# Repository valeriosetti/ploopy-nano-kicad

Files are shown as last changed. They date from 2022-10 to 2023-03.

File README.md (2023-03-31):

# What's Ploopy Nano?

Ploopy nano is a compact trackball mouse whose hardware project (electronics & mechanics) is completely open source. The original github project can be found here:

<https://github.com/ploopyco/nano-trackball>

# Why a clone?

There are a couple of reasons for this:

1. Albeit the original project is open, it's designed for Altium software. The goal of this project is to clone that design as much as possible, but in KiCAD

1. Since I would like to test the BTU mod and I had that printed from an external online service, it didn't make much sense in my opinion to buy the whole kit just for the PCB. That's why I prefered to do it on my own

# What are the differences with the original design?

For technical and components' availability reasons, this design is slightly different from the original version. Here's the main points:

* USB typeC connector instead of microUSB
    * that's my preference
    * of course the USB speed is not changed, it's just a connector replacement
* debug UART pinheader
    * it's always useful to have it in case some debug is required
* replaced the 3x2 programmer's pinheader with TPs
    * this is mostly for layout reasons: on one hand the original connector required through holes, whereas TPs are just on one side; on the other hand it's also more flexible to place those 6 TPs
* smaller crystal (in size)
    * I could not find the original crystal available on JLCPCB, so I switched to an equivalent one which unfortunately has smaller footprint

# Board's design

The placement of componenets on the board was obtained using FreeCAD:

* I loaded PCB's step file into FreeCAD
* Generated a 2D top view of the PCB
* Exported into DXF
* Impoted the DXF into KiCAD

Similarly I did also for the layout of the PCB itself. In this case:

* I imported the layout of the board in FreeCAD using KiCadStepUp plugin
* Ridesigned the edges of the board
* Exported again into the *kicad_pcb* file
* Reopened KiCAD with new shape

# Extra

The **jlcpcb** folder contain gerber, BOM and placement files I used to order from JLCPCB site. They have been automatically generated from the specific KiCAD's extension.

Some components, likes the ATmega32U4 or the LED, are not present in the BOM because they're out of stock on JLCPCB, so I'm planning to buy them separately and solder manually.

# Results

Since the description is quite long I decided to create a specific [readme file](result/README.md) for this in order to explain also the step I did for the bringup.

# Final thoughts

Even thought it's a nice project, there are a few things which might be known for anyone who attempts at building it:

* the ADNS-5050 is absolutely impossible to find, at least here in Europe. I ended up buying the ADNS-5020 which is pin to pin compatible, but also for that one it was a mess: the 1st order from Aliexpress was lost somewhere and the 2nd one took some time to be delivered (which is not so common nowadays when buying from Aliexpress)
* the 38 mm (1.5 inches) ball is not easy to find as well. I know, those are used for small billiard balls, but if you don't want to buy an entire set of billiard ball for just using 1, then good luck in finding something

In general I strongly suggest to take a look and consider also jfedor2's projects:
* they are based on a RP2040 microcontroller, which you can find at almost the same price of the ATMEGA, but it's way more powerfull 
* he provides the project directly for KiCAD with also gerber files for JLCPCB--> https://github.com/jfedor2/rp2040-pmw3360
* he used another sensor, PMW3360, which seems way more easy to find online

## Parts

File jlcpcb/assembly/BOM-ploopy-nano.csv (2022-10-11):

Comment | Designator | Footprint | LCSC
FerriteBead | FB1,FB2,FB3 | R_0603_1608Metric | C107335
0.1u | C1,C10,C2,C4,C5,C6,C7,C9 | C_0603_1608Metric | C14663
1u | C12,C3 | C_0603_1608Metric | C15849
20p | C13,C14 | C_0603_1608Metric | C1603
TYPE-C-31-M-12 | J4 | HRO_TYPE-C-31-M-12 | C165948
47 | R3,R4 | R_0603_1608Metric | C23164
5.1k | R7,R8 | R_0603_1608Metric | C23186
22 | R5,R6 | R_0603_1608Metric | C23345
10k | R1,R2 | R_0603_1608Metric | C25804
IP4220CZ6 | U2 | SOT95P275X110-6N | C558417
ECS-160-12-30B-AGM-TR | Y1 | Crystal_SMD_2520-4Pin_2.5x2.0mm | C655061
10u | C11,C8 | C_0603_1608Metric | C96446

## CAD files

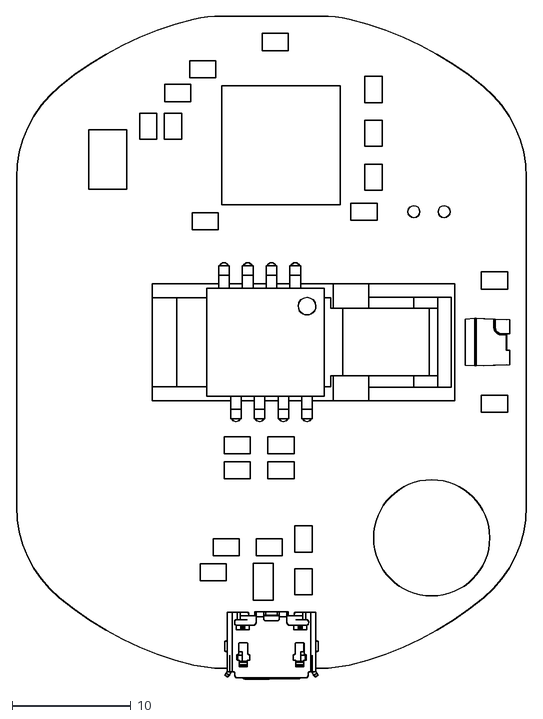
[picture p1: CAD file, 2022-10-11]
docs/original-pcb.dxf
43.0 x 55.9

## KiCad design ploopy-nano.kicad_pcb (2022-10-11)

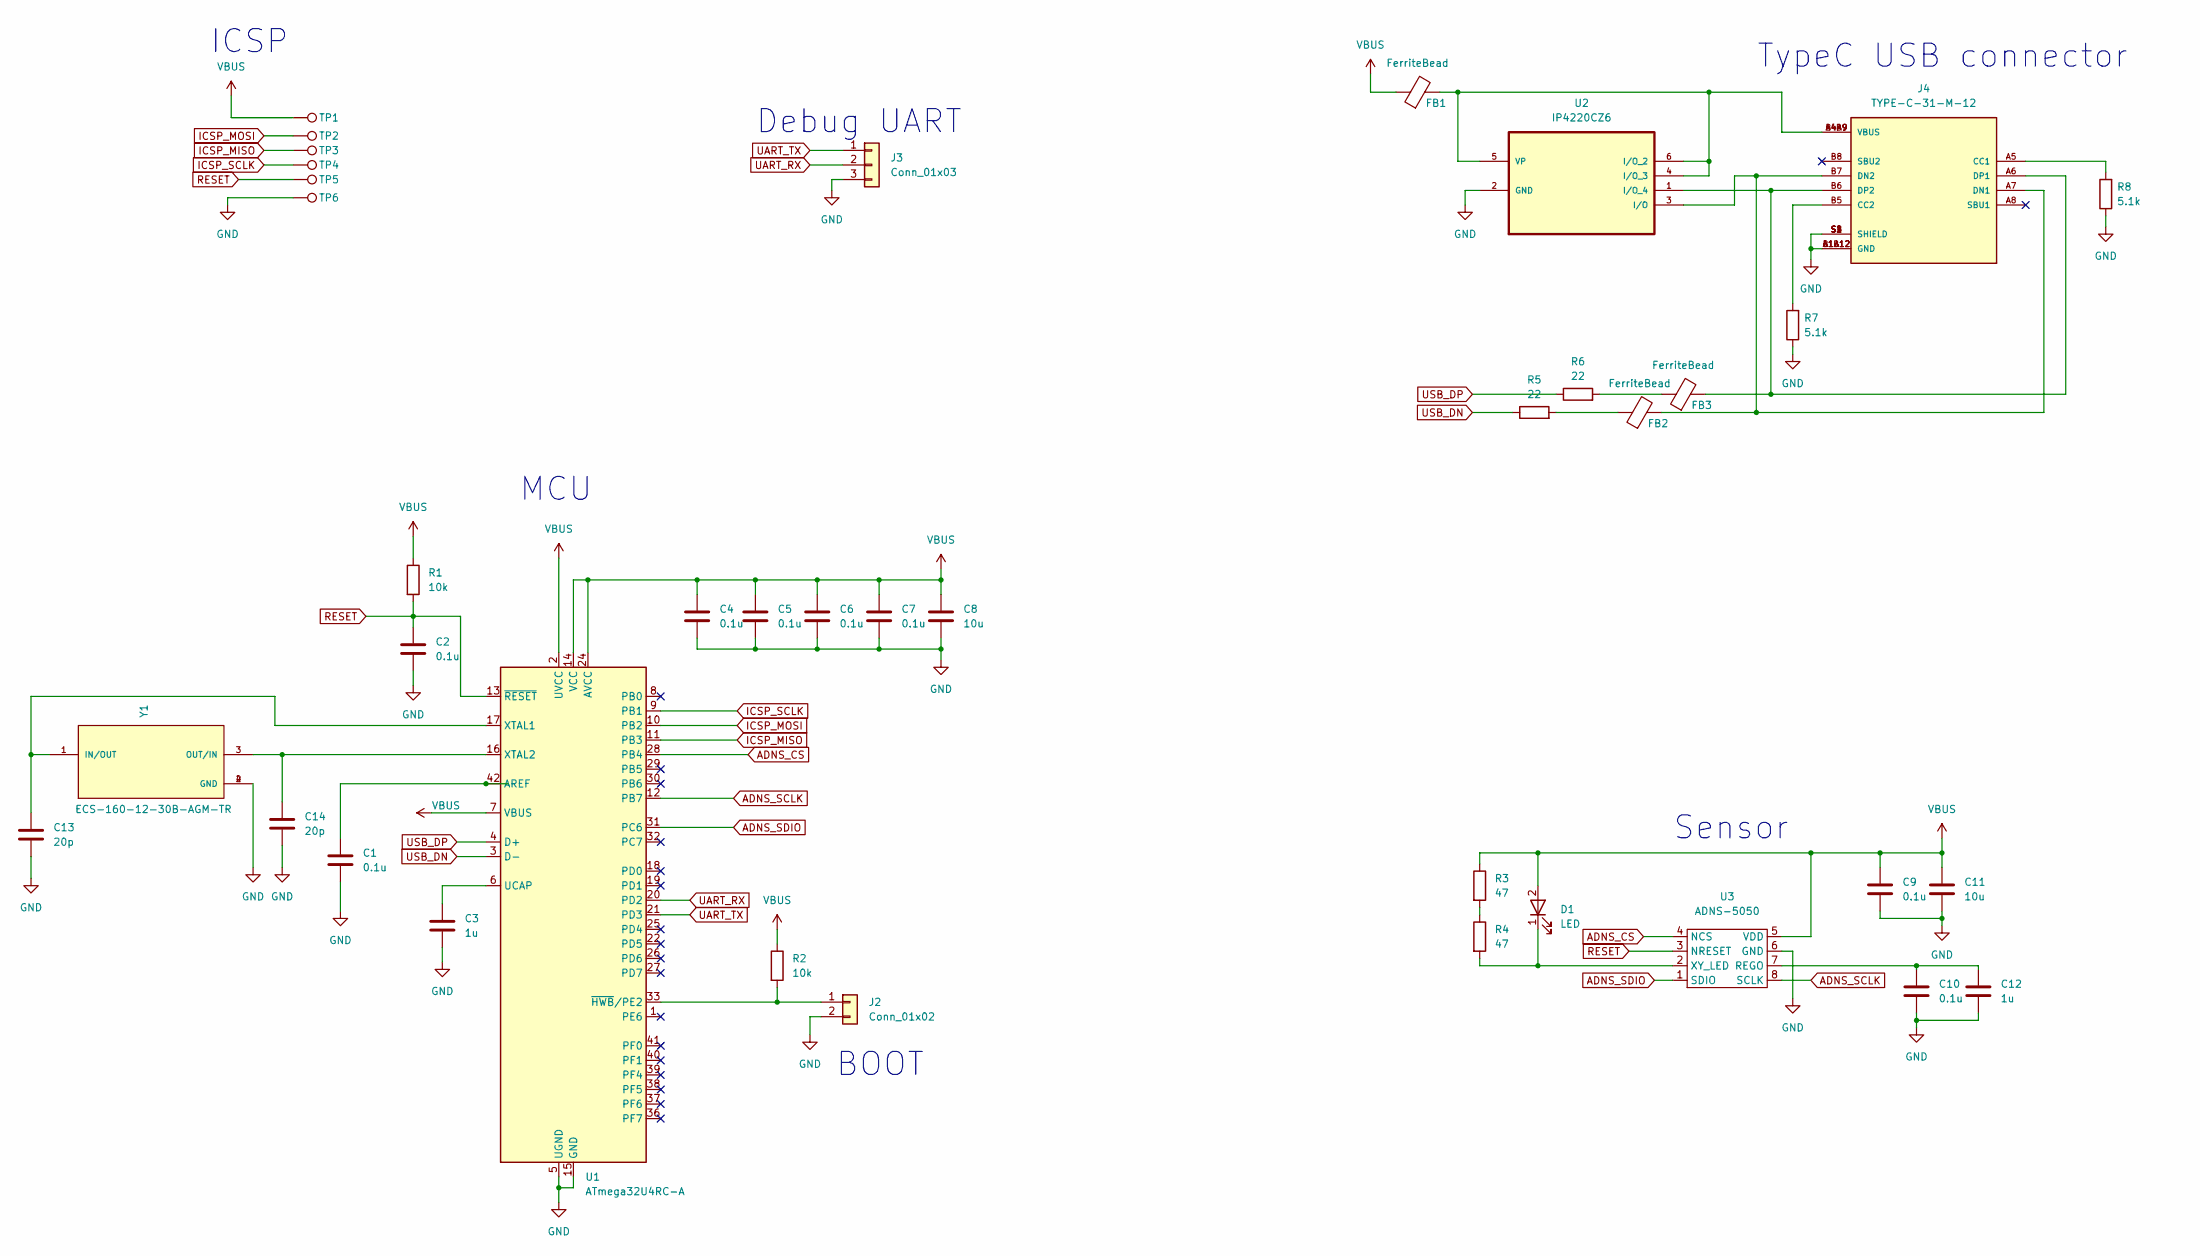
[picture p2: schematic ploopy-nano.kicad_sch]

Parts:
C1, C2, C4, C5, C6, C7, C9, C10: 0.1u; C_0603_1608Metric
C3, C12: 1u; C_0603_1608Metric
C8, C11: 10u; C_0603_1608Metric
C13, C14: 20p; C_0603_1608Metric
D1: LED; A67F
FB1, FB2, FB3: FerriteBead; R_0603_1608Metric
J2: Conn_01x02; PinHeader_1x02_P2.54mm_Vertical
J3: Conn_01x03; PinHeader_1x03_P2.54mm_Vertical
J4: TYPE-C-31-M-12; HRO_TYPE-C-31-M-12; PARTREV A
R1, R2: 10k; R_0603_1608Metric
R3, R4: 47; R_0603_1608Metric
R5, R6: 22; R_0603_1608Metric
R7, R8: 5.1k; R_0603_1608Metric
TP1, TP2, TP3, TP4, TP5, TP6: TestPoint; TestPoint_Pad_D1.0mm
U1: ATmega32U4RC-A; TQFP-44_10x10mm_P0.8mm
U2: IP4220CZ6; SOT95P275X110-6N; MPN IP4220CZ6
U3: ADNS-5050; ADNS-2610
Y1: ECS-160-12-30B-AGM-TR; Crystal_SMD_2520-4Pin_2.5x2.0mm

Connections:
ADNS_CS: U1.28 (PB4), U3.4 (NCS)
ADNS_SCLK: U1.12 (PB7), U3.8 (SCLK)
ADNS_SDIO: U1.31 (PC6), U3.1 (SDIO)
GND: C1.2, C2.2, C3.2, C4.2, C5.2, C6.2, C7.2, C8.2, C9.2, C10.2, C11.2, C12.2, C13.2, C14.2, J2.2, J3.3, J4.A1B12 (GND), J4.B1A12 (GND), J4.S1 (SHIELD), J4.S2 (SHIELD), J4.S3 (SHIELD), J4.S4 (SHIELD), R7.1, R8.1, TP6.1, U1.5 (UGND), U1.15 (GND), U1.23 (GND), U1.35 (GND), U1.43 (GND), U2.2 (GND), U3.6 (GND), Y1.2 (GND), Y1.4 (GND)
ICSP_MISO: TP3.1, U1.11 (PB3)
ICSP_MOSI: TP2.1, U1.10 (PB2)
ICSP_SCLK: TP4.1, U1.9 (PB1)
unnamed: C1.1, U1.42 (AREF)
unnamed: C3.1, U1.6 (UCAP)
unnamed: C10.1, C12.1, U3.7 (REGO)
unnamed: C13.1, U1.17 (XTAL1), Y1.1 (IN/OUT)
unnamed: C14.1, U1.16 (XTAL2), Y1.3 (OUT/IN)
unnamed: D1.1 (K), R4.2, U3.2 (XY_LED)
unnamed: FB1.2, J4.A4B9 (VBUS), J4.B4A9 (VBUS), U2.4 (I/O_3), U2.5 (VP), U2.6 (I/O_2)
unnamed: FB2.1, R5.2
unnamed: FB2.2, J4.A7 (DN1), J4.B7 (DN2), U2.3 (I/O)
unnamed: FB3.1, R6.2
unnamed: FB3.2, J4.A6 (DP1), J4.B6 (DP2), U2.1 (I/O_4)
unnamed: J2.1, R2.2, U1.33 (~HWB/PE2)
unnamed: J4.A5 (CC1), R8.2
unnamed: J4.B5 (CC2), R7.2
unnamed: R3.2, R4.1
RESET: C2.1, R1.2, TP5.1, U1.13 (~RESET), U3.3 (NRESET)
UART_RX: J3.2, U1.20 (PD2)
UART_TX: J3.1, U1.21 (PD3)
USB_DN: R5.1, U1.3 (D-)
USB_DP: R6.1, U1.4 (D+)
VBUS: C4.1, C5.1, C6.1, C7.1, C8.1, C9.1, C11.1, D1.2 (A), FB1.1, R1.1, R2.1, R3.1, TP1.1, U1.2 (UVCC), U1.7 (VBUS), U1.14 (VCC), U1.24 (AVCC), U1.34 (VCC), U1.44 (AVCC), U3.5 (VDD)

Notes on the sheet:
Debug UART
Sensor
BOOT
ICSP
TypeC USB connector
MCU

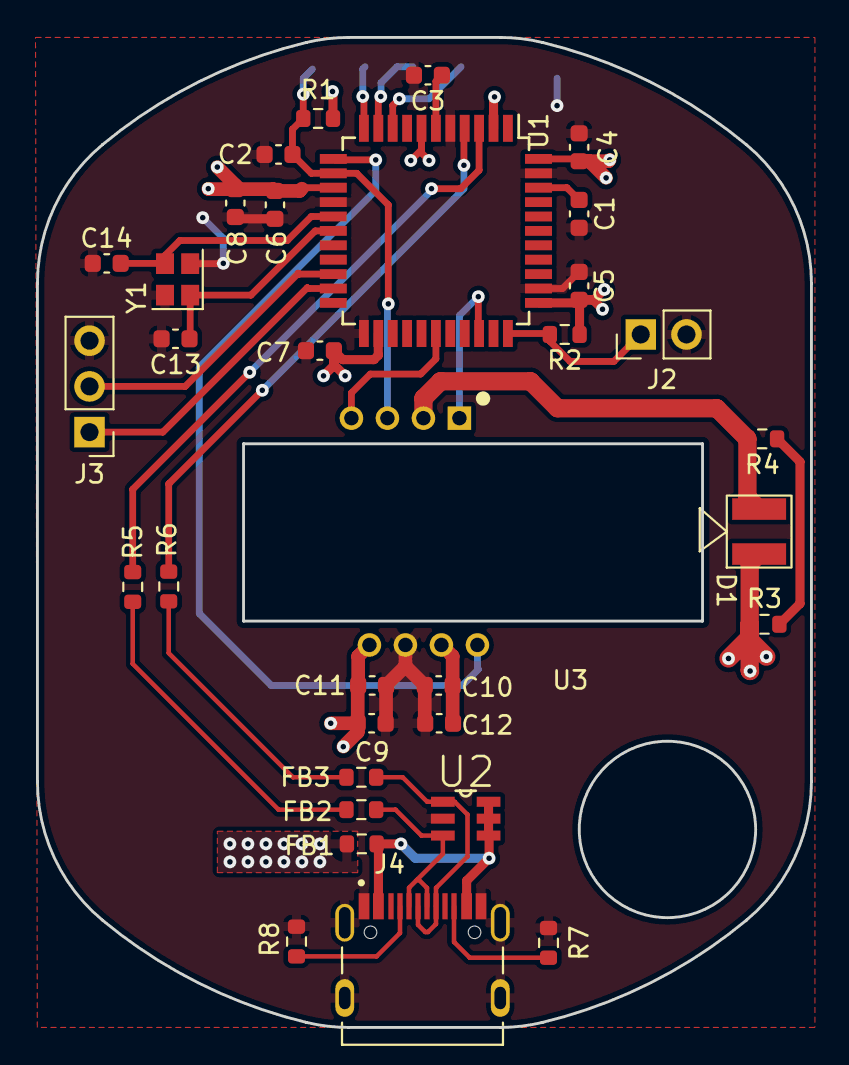
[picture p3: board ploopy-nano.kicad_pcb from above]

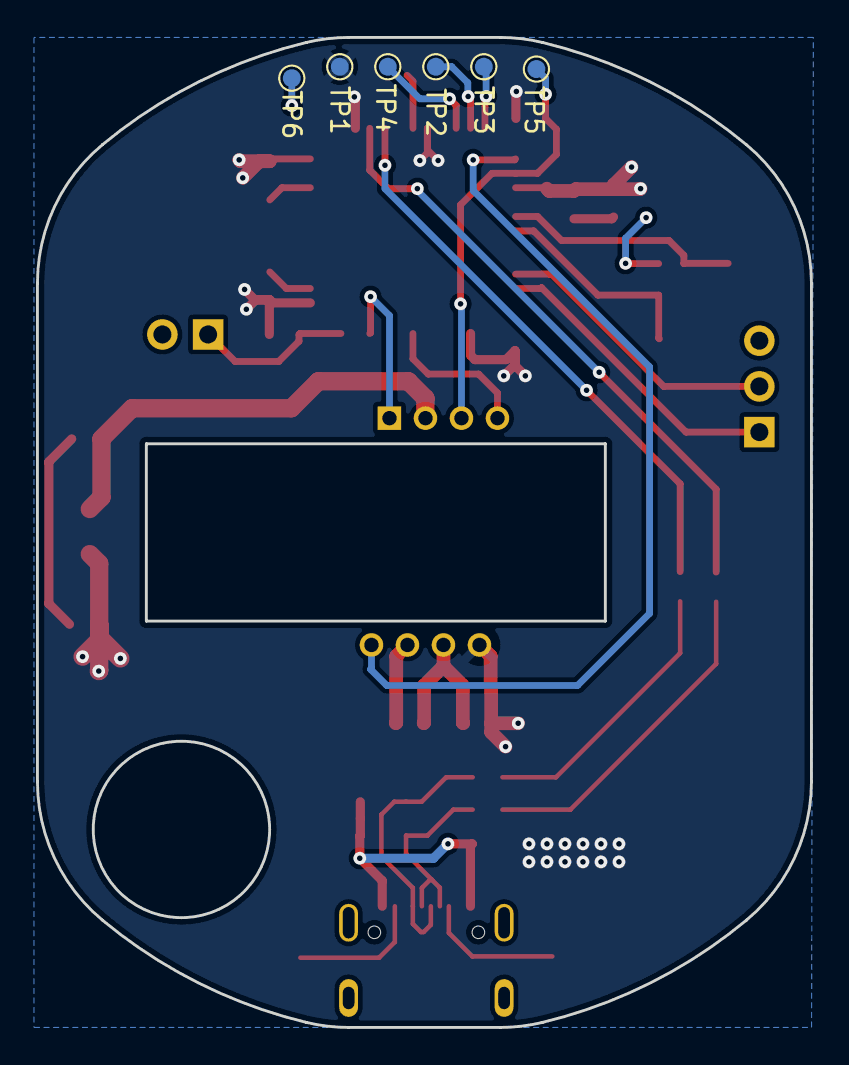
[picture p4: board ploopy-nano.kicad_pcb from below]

Board: 2 copper layers, 43.0 x 55.0 mm, 39 parts (6 on the bottom side), 28 nets.

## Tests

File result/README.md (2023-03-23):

# What the final board look like?

Well first of all here are (4 out of the 5) boards I received from JLCPCB

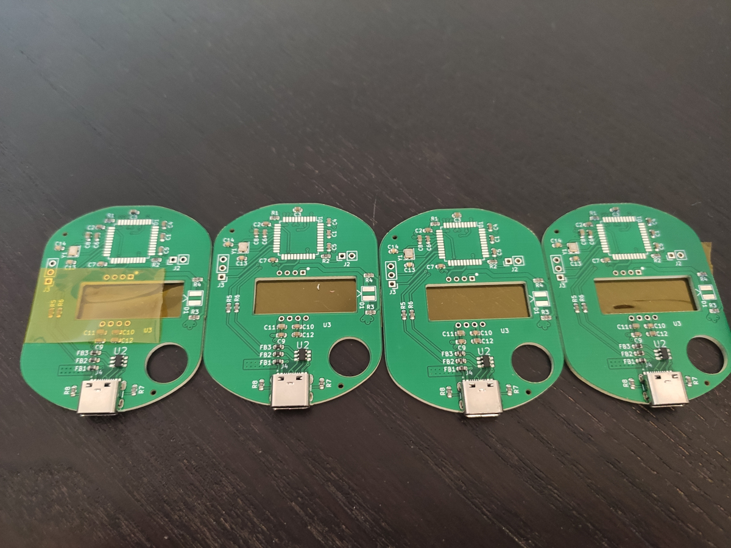
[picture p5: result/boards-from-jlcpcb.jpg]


Nothing to add here: they just look and work fine, as expected.

# Does the board fit into the 3D printed case?

Since I heavily copied the original design and placement the answer is yes, of course:

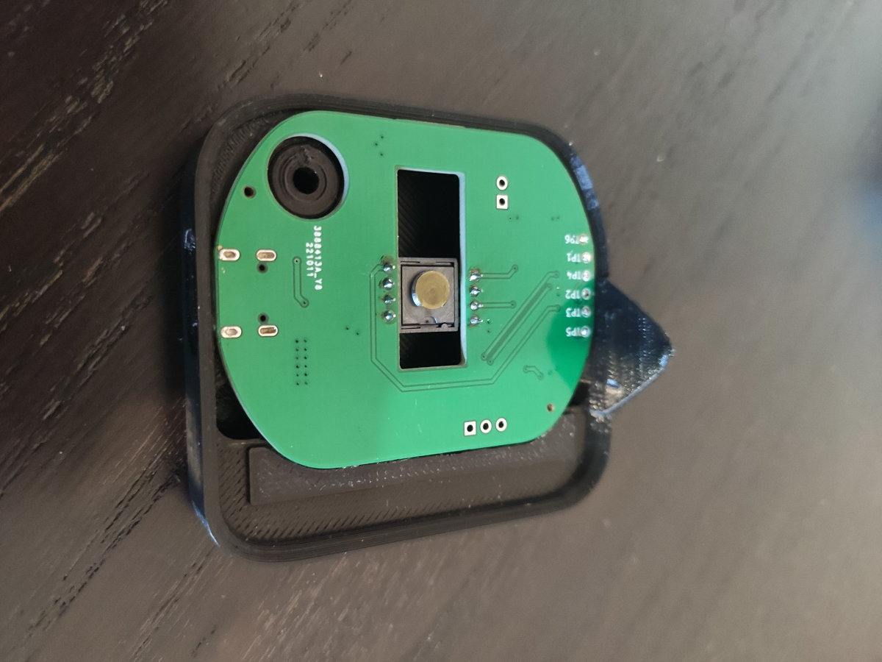
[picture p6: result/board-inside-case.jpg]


However, even though the board was OK, the 3D printed case was not at the beginning:

- the cut for the USB slot was for a microUSB, but I intentionally went for a typeC

- since I don't have a 3D printer, I had the case printed externally. It turned out that the board's holding parts were a bit too tall (so that the top part of the case was not closing properly)

Both of these problems were solved manually with the Dremel:

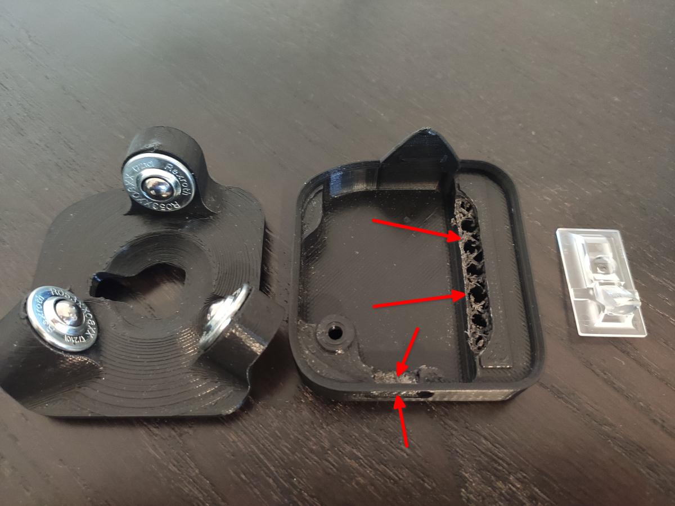
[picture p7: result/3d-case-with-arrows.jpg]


> The yellowish layer you see on the sensor is its original cover. I did not removed it yet because I'm still waiting for the trackball to arrive so until then I'll keep the protection on.

# Schematic fixes

Only a major fix was required compared to the original design:

- **do not mount** C13 and C14 since otherwise the oscillator does not start (verified with oscilloscope)

Then there is also another one, but this is due to the fact I was not able at all to find the ADNS-5050 component, so I replaced it with ADNS-5020 which is pin-to-pin compatible. In case you do the same then **do not install** also R3 and R4.

# How to build the FW?

You can easily download QMK firmware from its repository, checkout at the `master` branch and build it with:

```
util/docker_cmd.sh make clean && util/docker_cmd.sh qmk compile -kb ploopyco/trackball_nano/rev1_001 -km default:production
```

The `production` keyword was added because we're dealing with a completely new MCU which does not have a bootloader yet (well, not the one QMK expects) so we build both the FW and the bootloader at once.

> Yes, I used Docker. You can run the same commands without it, but perhaps you will need to install required packages.

# How to flash the board?

Luckily there is no need for an external fancy programmer since the board can be programmed with `avrdude` using a RaspberryPi:

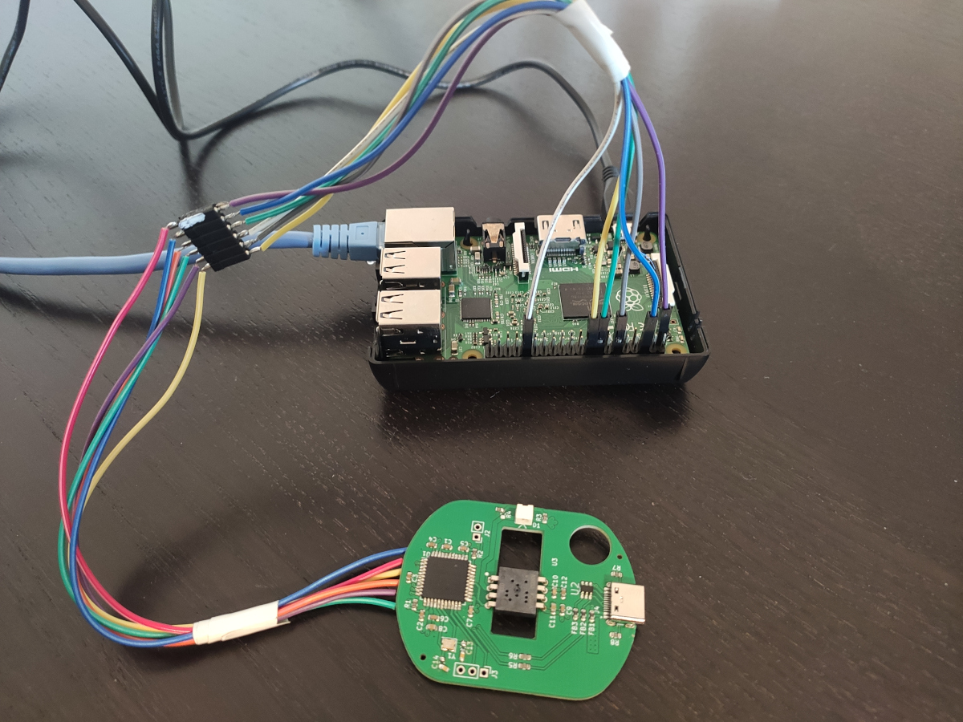
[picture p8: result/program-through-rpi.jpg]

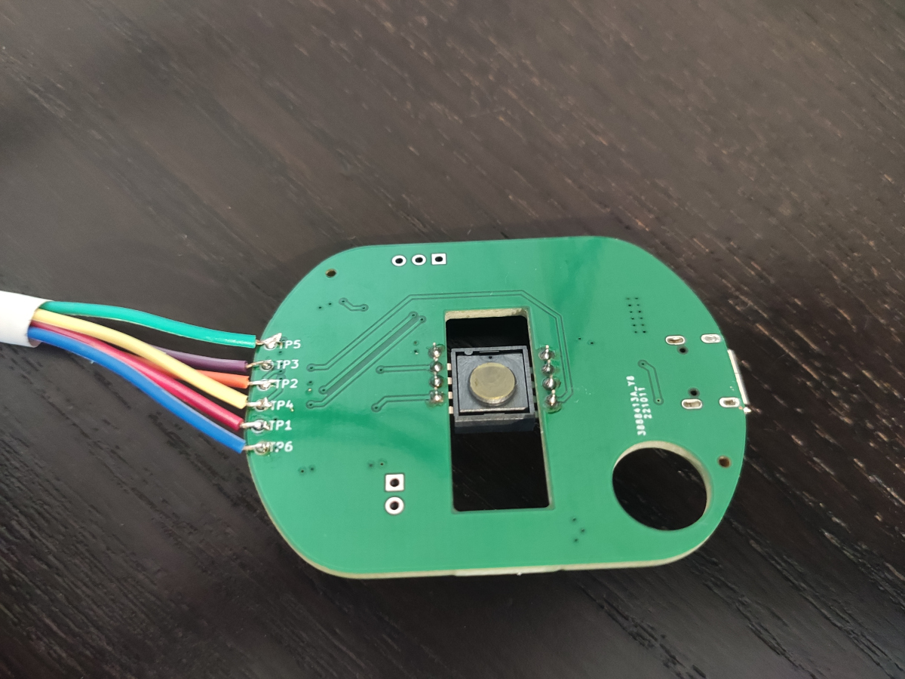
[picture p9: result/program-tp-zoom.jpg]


---
**WARNING**

In order not to uncorrectly power either the ploopy nano or the RPi, I strongly suggest to:

- disconnect the RPi from any power supply
- connect the RPi to the Ploopy
- connect power to the RPi and turn it on

---

Here is how I did the connection (but you can change it on the RPi side - check `avrdude` instructions for this):

| RPi pin # | wire color (RPi/Ploopy) | Ploopy TP
|---|---|---
| 1 | violet/red | 1
| 6 | blue/blue | 6
| 12 | gray/violet | 3
| 16 | green/orange | 2
| 18 | yellow/yellow | 4
| 32 | white/green | 5

(I added also the wirecolors in the table above so that you can also double check with the pictures).

Once you got the connection done and RPi turned on, you can SSH into it and the issue the following command to program your board:

```
sudo avrdude -p atmega32u4 -C ~/avrdude_gpio.conf -c pi_1 -v -U flash:w:ploopyco_trackball_nano_rev1_001_default_production.hex:i -U lfuse:w:0x5E:m -U hfuse:w:0x99:m -U efuse:w:0xC3:m -U lock:w:0x3F:m
```

---
**WARNING**

Of course care should be taken also when powering down:

- turn off the RPi first
- disconnect all power cables from it
- disconnect Ploopy

---

## What are those `-U lfuse:w:0x5E:m -U hfuse:w:0x99:m -U efuse:w:0xC3:m` used for programming the MCU?

The ATMEGA32U4 has some internal fuses that are used to set some configuration in a non-volatile way (i.e. not lost by resetting the board). These configurations include the crystal oscillator and by default the microcontroller is set to use the internal RC one (check the datasheet for this):

- L-fuse = 0x52
- H-fuse = 0x99
- E-fuse = 0xFB

Internal RC oscillator is **not** OK for use with USB since it is not stable enough for that purpose and moreover the FW expects something at higher speed. That's why we set:

- L-fuse = 0x5E
- H-fuse = 0x99
- E-fuse = 0xC3

Of course these changes were also suggested in the Ploopy project's wiki:
<https://github.com/ploopyco/classic-trackball/wiki/Appendix-D%3A-Programming-QMK-on-Older-Ploopy-Devices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>

and elsewhere, like:
<https://www.reddit.com/r/olkb/comments/8sxgzb/replace_pro_micro_bootloader_with_qmk_dfu/>)

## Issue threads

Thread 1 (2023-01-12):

Adding buttons

sommerper, 2023-01-12:
Hi!

This looks interesting!

I was wondering if there is a way to add buttons to this and make a complete trackball unit. I couldn't quite figure that out just by looking at the pcb in kicad.

Thanks!

valeriosetti, 2023-01-16:
Hi!!

Yes, adding buttons is something I would definitely want to try in the future (actually 3/4 buttons and a knob for scrolling).

On one hand I didn't have the time to test the trackball itself because I still did not receive the ADSN5050 sensor. The first time I bought it from Ebay, but after 2 months waiting I was just notified that the box was lost :/. I did a 2nd purchase recently from Aliexpress and I hope this time it will arrive (sooner or later), so that I can test everything.
So far I've only be able to verify that the programming of the MCU works, but nothing more.

However the bigger problem for me for such kind of projects is always the mechanical design part, not the SW or electronics. Adding one or more buttons is something easy from the SW/electronics point of view, but I have very little clue on how to modify the case in order to adapt for that. Recently I tried some tutorial for FreeCAD, but I fear I'm still quite far for being able to modify the case properly :/

BTW, I don't know if you already know [this github repo](https://github.com/jfedor2), but it contains several trackball designs very similar to the Ploopy one which integrates also buttons!
Perhaps he already designed something close to what you are looking for ;)

sommerper, 2023-01-16:
Thanks for the detailed reply! Ok, I'll keep an eye on the project for now and see how it develops.
I'm actually less worried about the case because mostly I end up doing my own design anyway.
And thank you for the link. I had indeed not seen that yet and it also contains some cool trackballs.

valeriosetti, 2023-01-17:
Ok, if the mechanical design is not a problem for you, the from the firmware point of view I think the design is based in QMK. They have a fork of the main repository [here](https://github.com/ploopyco/qmk-firmware-ploopyco-dev) and inside that one there are `ploopy/*` specific branches such as `ploopyco/mini_fixes`.

I'm really a beginner on QMK and I never tried to build a mouse before. However I added mouse buttons to my ErgoDash keyboard, and it was super easy.

valeriosetti, 2023-01-17:
PS = in case in the future you want to try to build the ploopy nano yourself, please consider replacing the optical sensor (ADSN5050) with something newer and easier to buy. As I mentioned earlier, I didn't consider this during my development and now I'm stuck in buying that component. Perhaps PMW3360 and similar are much easy to find (also check which one is already supported in QMK if you don't want to write too much code, of course)

sommerper, 2023-03-16:
Thanks for your suggestion! And sorry for not closing this earlier!

Closed 2023-03-16.

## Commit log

2022-10-11 pcb: removed bak files
2022-10-11 readme: updated with board's design details
